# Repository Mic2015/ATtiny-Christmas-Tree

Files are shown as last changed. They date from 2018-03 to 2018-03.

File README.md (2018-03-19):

# ATtiny-Christmas-Tree
Here is a project to create a mini Christmas tree (32x32mm) animated.
with these 8 LEDs smd he chained several figures you will also see the big version which measures about 7 cm
everything is programmed with Arduino and the core for Tiny
there is also a program with Delphi 7 that allows you to create and test your animations and to release the arduino code

Voici un projet qui permet de créer un mini sapin de Noël (32x32mm) animé.
avec à ces 8 LEDs smd il enchaine plusieurs figures vous verez aussi la version big qui mesure environ 7 cm
le tout est programmé avec Arduino et le core pour les Tiny
il y a aussi un programme céé avec delphi 7 qui permet de créer et tester   vos animation et de sortir le code arduino

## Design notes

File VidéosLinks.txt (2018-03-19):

Tiny Christmas Tree Attiny13-2015
https://youtu.be/Hd_K3JuI6Yk
Tiny Christmas Tree Attiny13-2016
https://youtu.be/pQZAkw4r5nw
Tiny Christmas Tree Attiny13-Construction-2016
https://youtu.be/IFs6D08m9vI
Core Attiny for Arduino
https://youtu.be/g4TdmSgLC6U
Animations Maker For Tiny Tree - logiciel de construction d'Animation pour Tiny Tree
https://youtu.be/VrdeUw6v0cw

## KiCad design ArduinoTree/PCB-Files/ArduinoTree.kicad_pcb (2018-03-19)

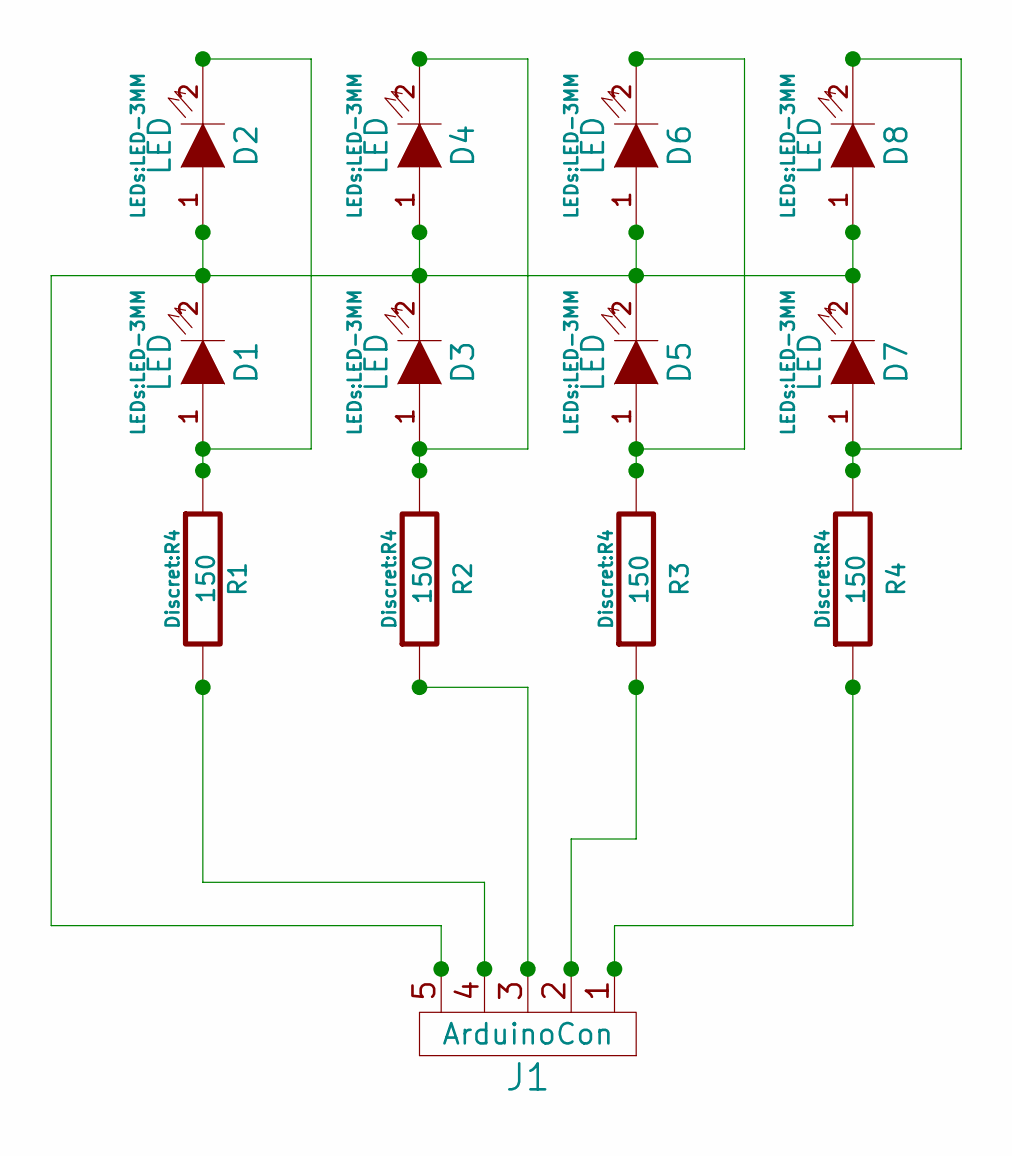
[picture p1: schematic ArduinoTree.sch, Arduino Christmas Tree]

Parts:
D1, D2, D3, D4, D5, D6, D7, D8: LED; LED-3MM
J1: ArduinoCon; pinhead-1X05
R1, R2, R3, R4: 150; R4

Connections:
unnamed: D1.1 (A), D2.2 (K), R1.1
unnamed: D1.2 (K), D2.1 (A), D3.2 (K), D4.1 (A), D5.2 (K), D6.1 (A), D7.2 (K), D8.1 (A), J1.5
unnamed: D3.1 (A), D4.2 (K), R2.2
unnamed: D5.1 (A), D6.2 (K), R3.2
unnamed: D7.1 (A), D8.2 (K), R4.2
unnamed: J1.1, R4.1
unnamed: J1.2, R3.1
unnamed: J1.3, R2.1
unnamed: J1.4, R1.2

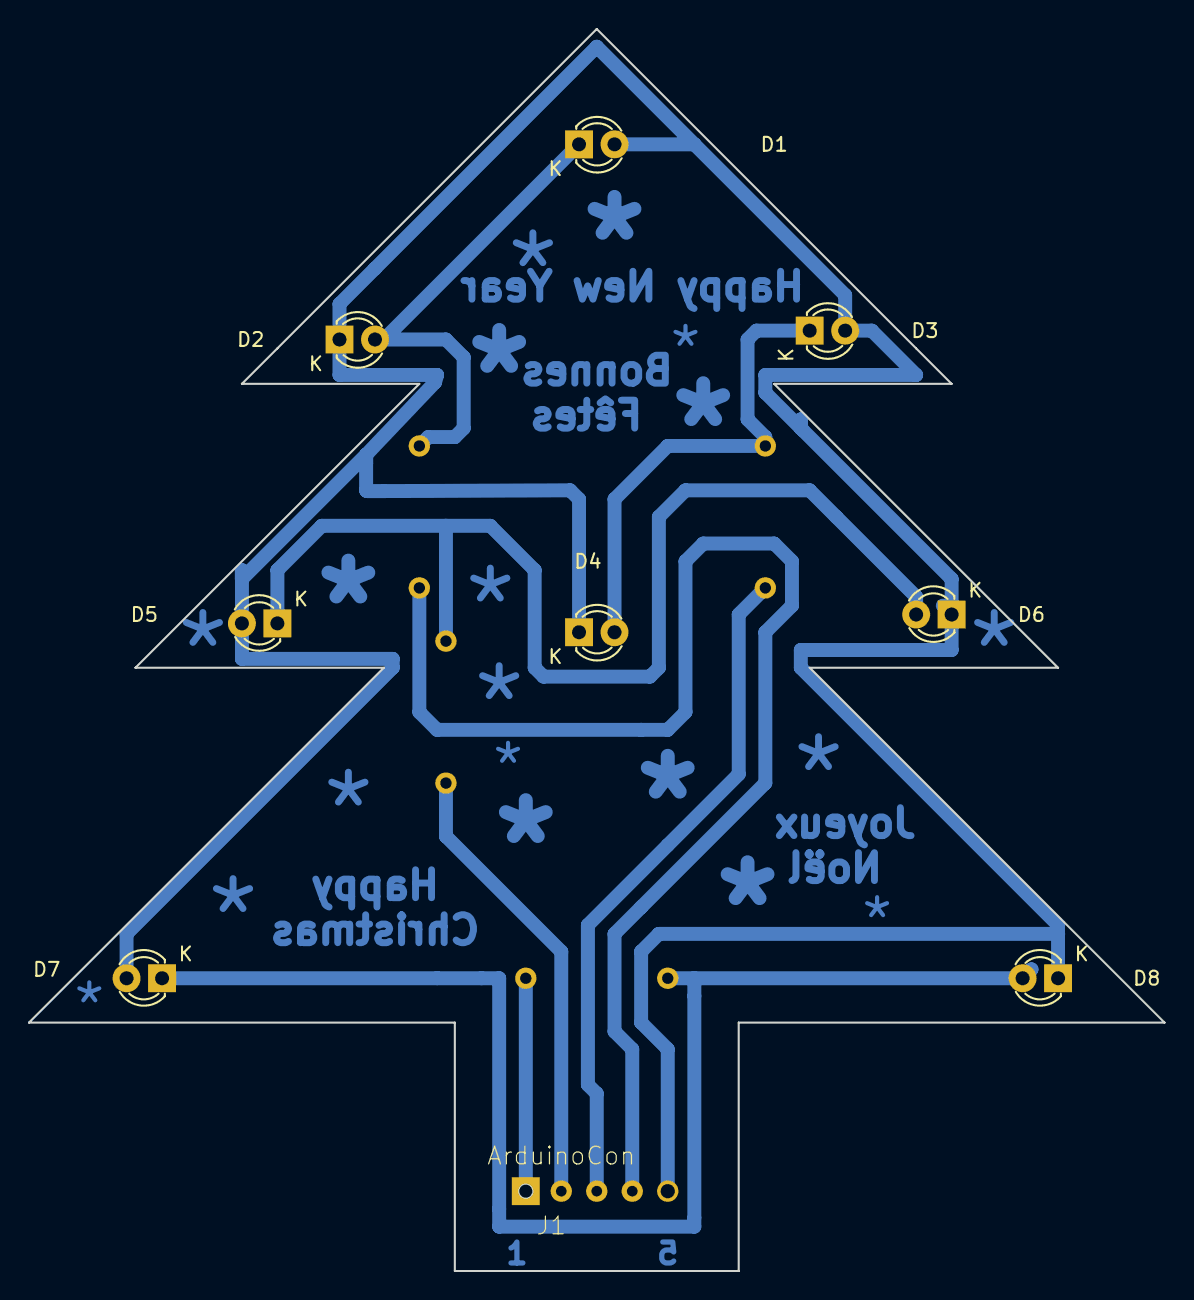
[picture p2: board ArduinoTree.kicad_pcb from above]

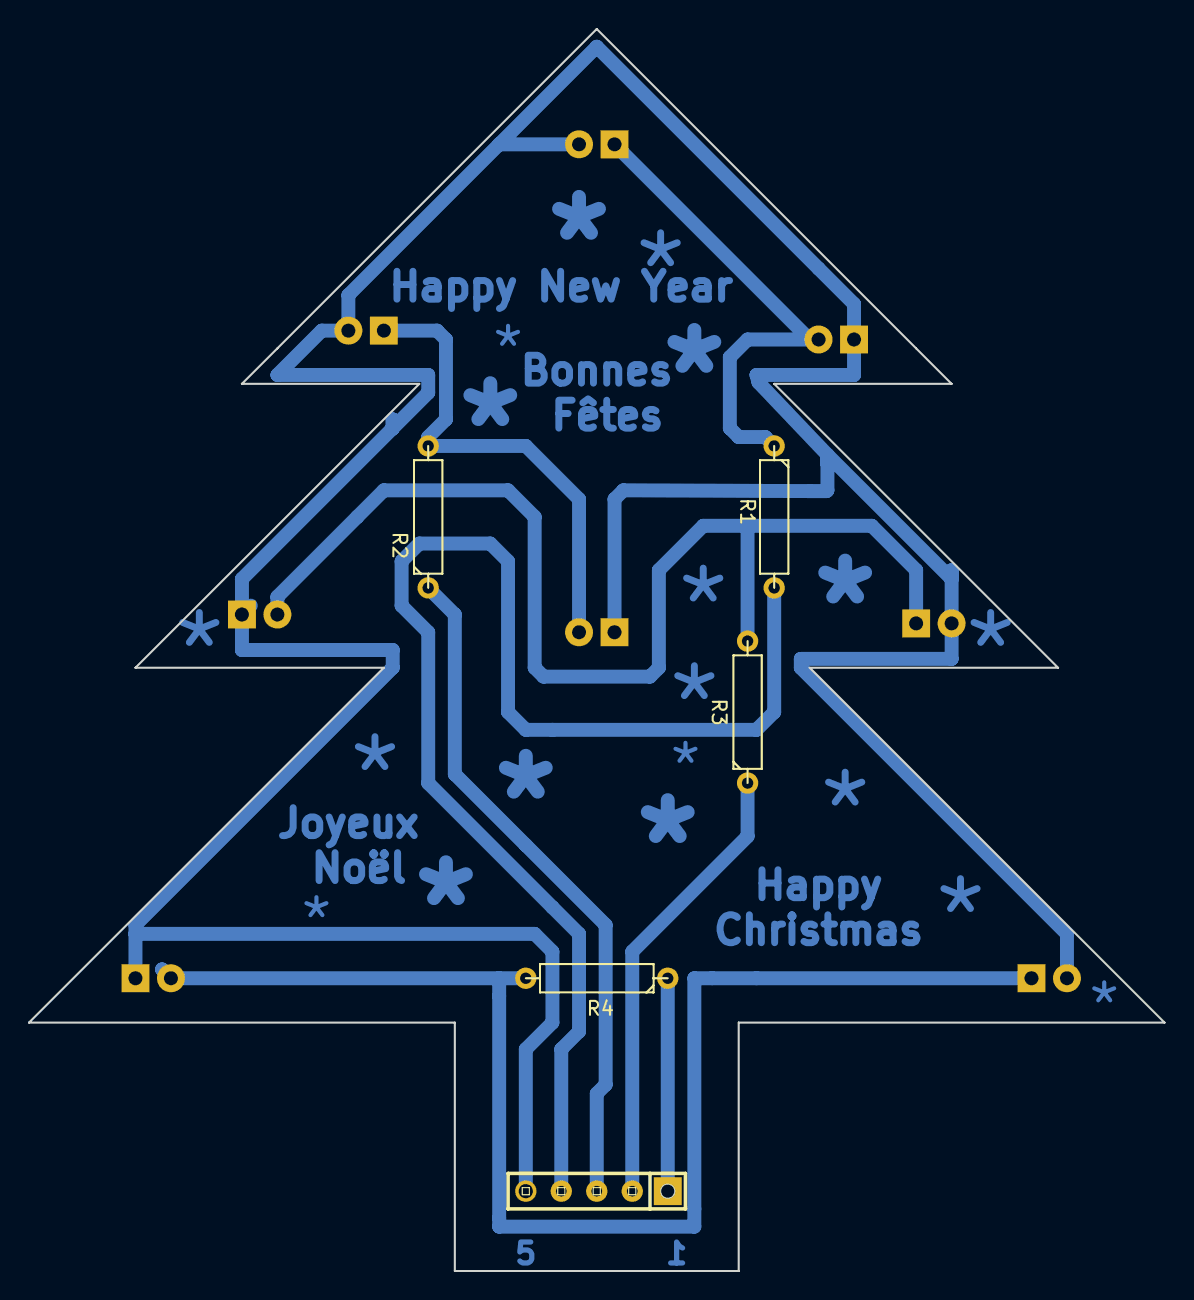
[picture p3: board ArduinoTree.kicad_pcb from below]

Board: 2 copper layers, 81.3 x 88.9 mm, 13 parts (5 on the bottom side), 9 nets.

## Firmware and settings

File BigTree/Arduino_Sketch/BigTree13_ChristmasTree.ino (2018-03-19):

/*
 * TreeOneByOne.c for 
 *
 * Created: 18/11/2015 with Arduino 1.06
 *  Author: Mic-Josi 
 * ATtiny13
 * for Big Tree PCB uniquement
 *
*Cette animation est faite pour L'ATtiny13 (1K de mémoire flash)
 *Si vous avez ajouté ses figures et que l'animation reste figée au premier test, cela est dû à la variable spd (vitesse)
 *qui utilise plus ou moins de mémoire .
 *Par exemple 150 prend plus de mémoire que 65.
 *La seule solution est d'utiliser un ATtiny25 ou  ATtiny45 ou ATtiny85 qui possèdent beaucoup plus de mémoire; respectivement 2K 4k et 8K de mémoire flash.
 This animation is for the ATtiny13 (flash memory 1K)
If you added his figures and the animation remains frozen in the first test, this is due to the variable spd (speed)
using more or less memory.
For example 150 takes more memory than 65.
The only solution is to use an ATtiny25 or ATtiny45 or ATtiny85 which have much more memory; respectively 2k ,4k, 8k flash memory. 
 */

/*
 * TIP from http://homecircuits.eu/blog/low-power-picopower-attiny13a/
 * Reduce the power consumption of an Attiny13
 * ADCSRA &= ~(1<<ADEN); //Disable ADC désactive l'ADC
 * ACSR = (1<<ACD); //Disable the analog comparator Désactive le comparateur anologique
 * DIDR0 = 0x3F; //Disable digital input buffers on all ADC0-ADC5 pins désactive les entrée buffer de tous les ADC0-ADC5.
 */
 
/*
These inused #define are for using with Amtel Studio 6 only
Ces defines sont à utiliser uniquement avec Amtel Studio 6 
# define __DELAY_BACKWARD_COMPATIBLE__ 
# define F_CPU 8000000UL
# include <avr/io.h>
# include <util/delay.h>
# define byte uint8_t
*/

//Arduino defines
#include <avr/pgmspace.h>
#define LED_COUNT 9
#define DDR_BYTE 0
#define PORT_BYTE 1



const byte matrix[LED_COUNT][2] PROGMEM = {
	
	// DDR_BYTE   	PORT_BYTE                                        
	{0b00010001	, 0b00010000},//L0-PB4               0                 
	{0b00010001	, 0b00000001},//L1-PB4           "     "                   
	{0b00001001	, 0b00001000},//L2-PB3          " 1    2 "               **     Pin-Tree     **
	{0b00001001	, 0b00000001},//L3-PB3        "      3     "                 L0+ L1- Pin 3
	{0b00000101	, 0b00000100},//L4-PB2      " 4            6 "               L2+ L3- Pin 2
	{0b00000101	, 0b00000001},//L5-PB2     "                   "             L4+ L5- Pin 7
	{0b00000011	, 0b00000010},//L6-PB1    " 5                 7  "           L6+ L7- Pin 6
	{0b00000011	, 0b00000001},//L7-PB1   """""""""""""""""""""""""""   ** +- Commun PB0 Pin 5 **
          
};		


//*******************************************************
void turnOn( byte led ) // PBx selection
{
  DDRB = pgm_read_byte (&( matrix[led][DDR_BYTE]));
  PORTB = pgm_read_byte (&(matrix[led][PORT_BYTE]));
}
//*******************************************************


//*******************************************************
// frame- nombre de fois la figure, l1 à l8 = état des LED, spd = temps d'llumage d'une LED en mili-second
void SomeOne (byte frame,byte l1,byte l2,byte l3,byte l4,byte l5,byte l6,byte l7,byte l8,byte spd) // some LEDs ON one by one spd time
{  
	
    int figure [9]= {0,0,0,0,0,0,0,0,0};
	
	int light = 0;
	int allume = 0;
	byte l9 = 8;
	while (light < frame)
	{
		for( byte l = 0; l < LED_COUNT; l++ )
		
	  	{
			switch (l)
			{
			case 0:
			figure [l] = l1;
			break;	
			
			case 1:
			figure [l] = l2;
			break;
			
			case 2:
			figure [l] = l3;
			break;
			
			case 3:
			figure [l] = l4;
			break;
			
			case 4:
			figure [l] = l5;
			break;
			
			case 5:
			figure [l] = l6;
			break;
			
			case 6:
			figure [l] = l7;
			break;
			
			case 7:
			figure [l] = l8;
			break;
			
			case 8:
			figure [l] = l9;
			break;
			} 
			
			
		}
		for( byte l = 0; l < LED_COUNT; l++ )
		{
		 allume = figure[l];
		 turnOn(allume);
		 delay(spd);
		} 
		
		light ++;
	}
	delay(50);

}

 //*******************************************************



void setup()
{
 ADCSRA &= ~(1<<ADEN); //ADC off  
}


//*******************************************************

//=======================================================
void loop()
{
  /* 0 à 7 emplacement d'allumage de la LED,8 LED éteinte
    0 to 7 lighting location of the LED, 8 LED off */
	
//===================== Big Christmas Tree Only ============================
SomeOne (8,1,0,3,2,5,4,7,6,150);
SomeOne (8,1,0,3,2,5,4,7,6,65);
SomeOne (15,1,0,3,2,5,4,7,6,35);
SomeOne (100,1,0,3,2,5,4,7,6,1);
SomeOne (8,1,0,3,8,8,8,8,8,70);
SomeOne (8,0,3,2,8,8,8,8,8,70);
SomeOne (8,7,6,1,5,4,1,0,3,50);
SomeOne (8,8,7,6,2,2,5,4,1,60);
SomeOne (8,0,3,5,4,7,6,1,2,110);
SomeOne (8,7,2,6,0,1,3,5,4,110);
//=========================================================================
}
//more trames with ATtiny45 or 85
//plus de figure avec ATtiny45 or 85
